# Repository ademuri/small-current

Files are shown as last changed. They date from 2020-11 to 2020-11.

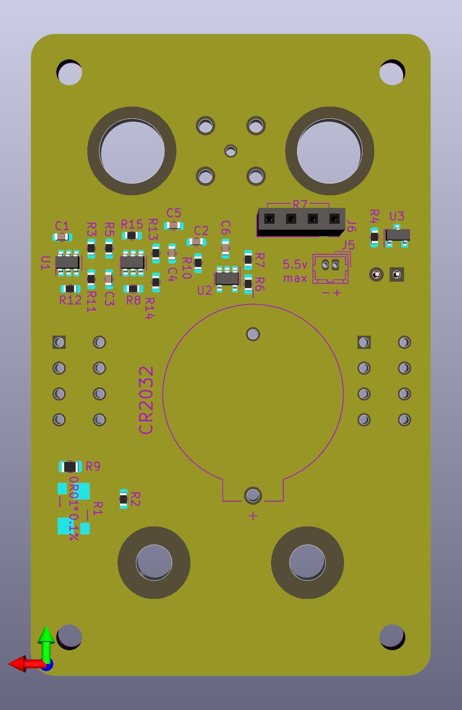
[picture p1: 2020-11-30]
ref/board back.jpg

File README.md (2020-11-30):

# smallCurrent

This library is an adaptation of the circuit schematics of the
[tinyCurrent](https://github.com/nfhw/tinycurrent) project by n-fuse, which in
turn are adapted from [uCurrent
Gold](https://www.eevblog.com/projects/ucurrent/) by Dave Jones of EEVBlog.

This is functionally equivalent to the tinyCurrent. The BOM is optimized for
ordering from Digikey (easier to source the components in North America). It has
also been redesigned in the free and open-source KiCAD, rather than Altium, so
that making changes is more accessible.

## License

This work is licensed under a [Creative Commons Attribution-ShareAlike 3.0 Unported](https://creativecommons.org/licenses/by-sa/3.0/).

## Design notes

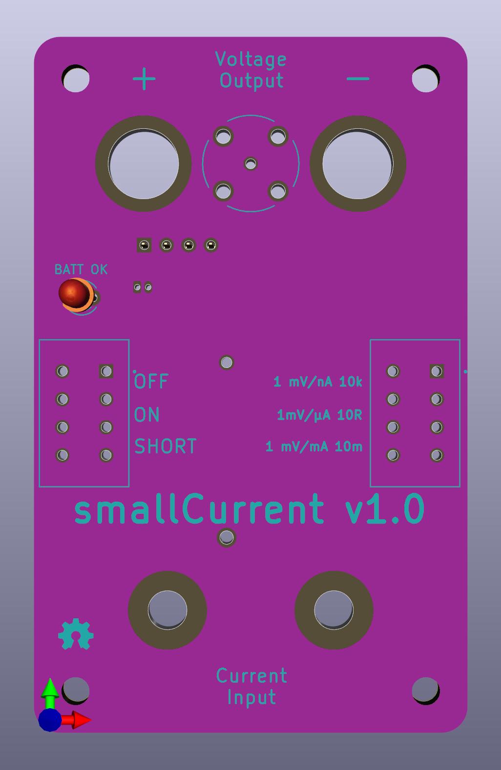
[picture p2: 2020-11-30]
ref/board front.jpg

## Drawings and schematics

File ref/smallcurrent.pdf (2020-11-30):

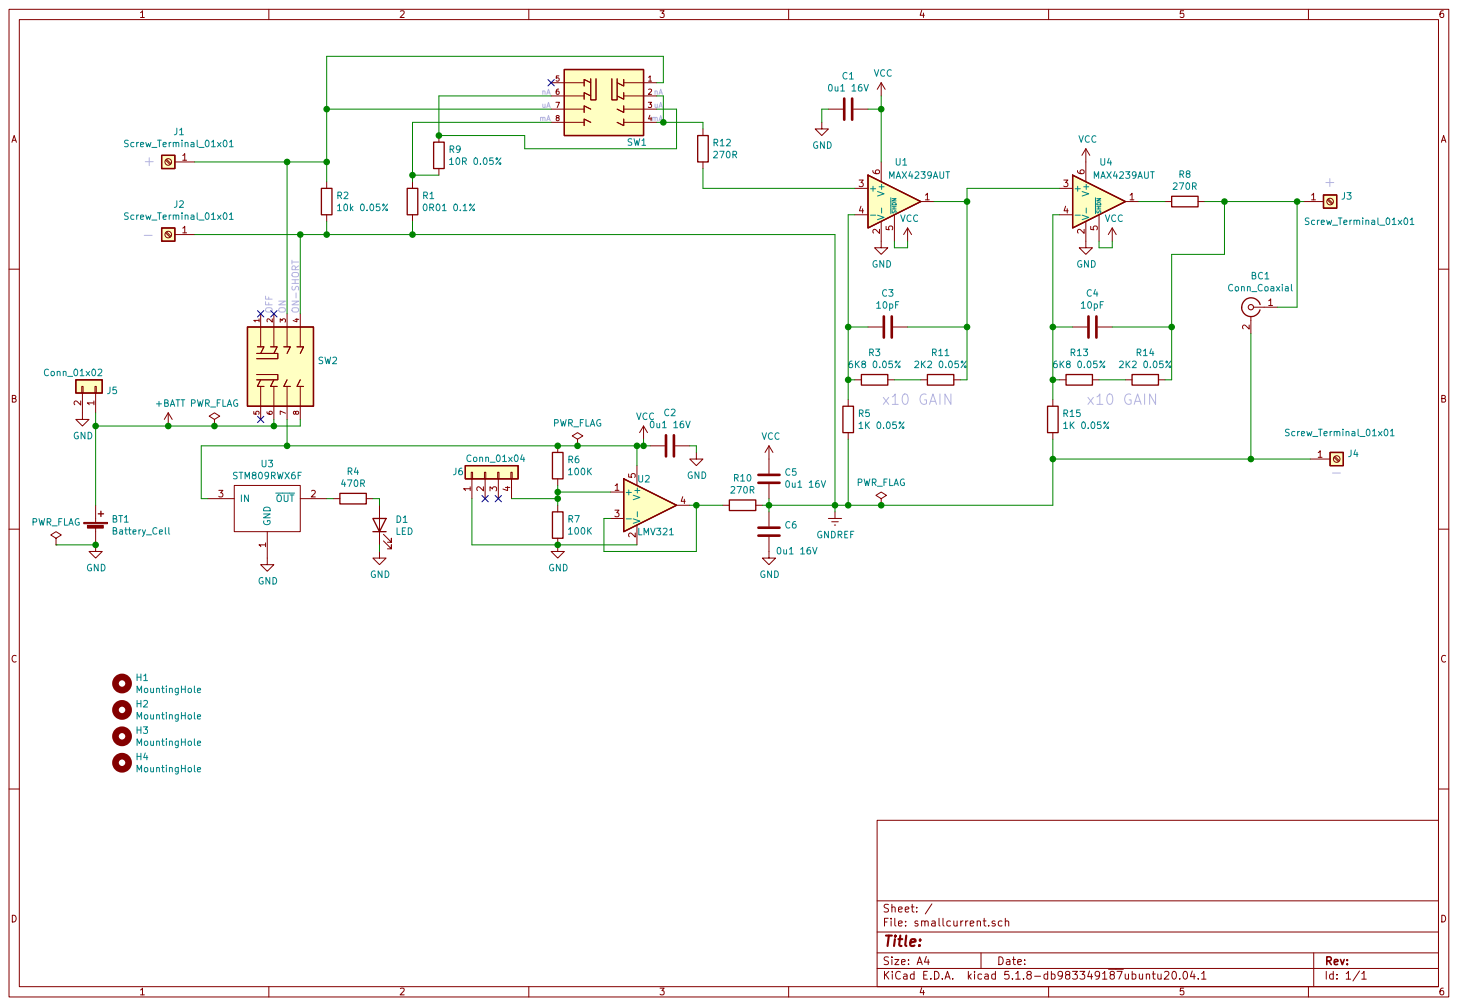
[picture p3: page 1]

Id: 1/1 Title: File: smallcurrent.sch Sheet: / GND

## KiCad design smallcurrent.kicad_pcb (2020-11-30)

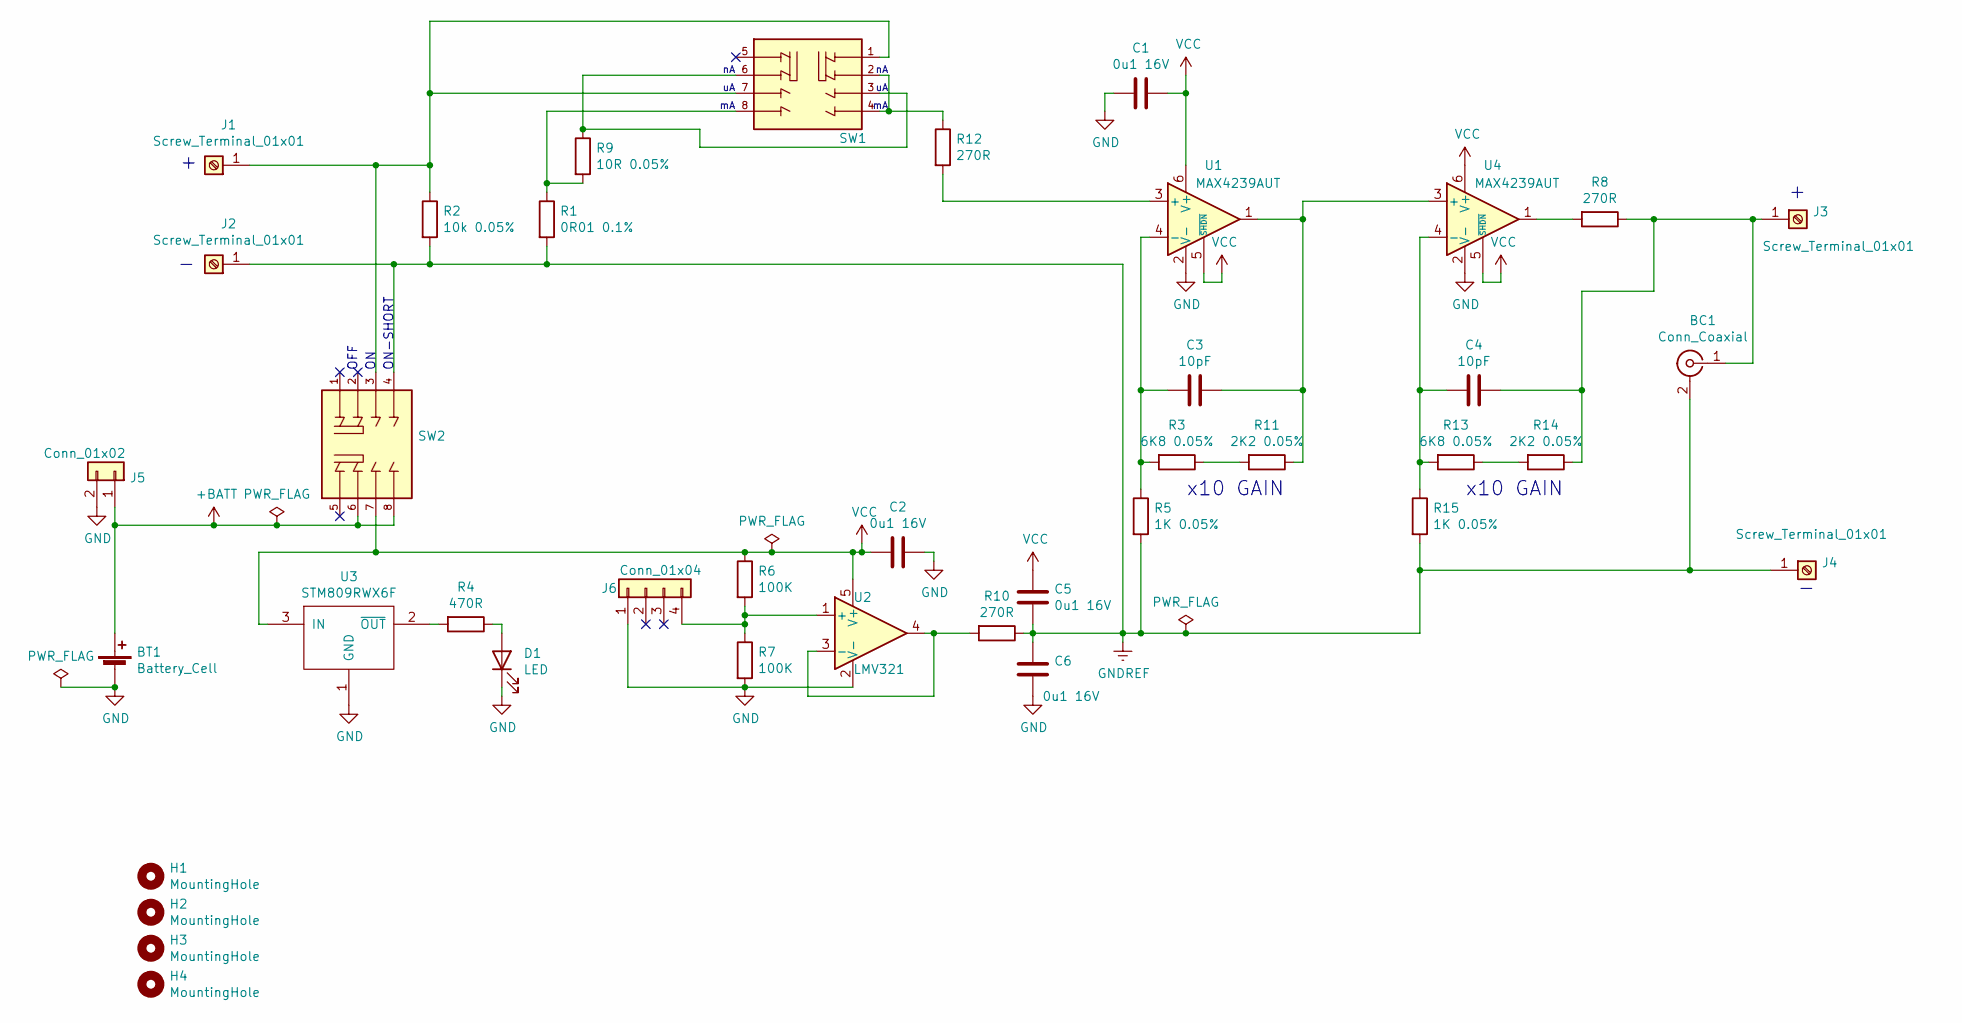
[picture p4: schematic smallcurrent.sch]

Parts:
BC1: Conn_Coaxial; TE_5-1634503-1
BT1: Battery_Cell; BAT_BS-7
C1, C2, C5, C6: 0u1 16V; C_0603_1608Metric
C3, C4: 10pF; C_0603_1608Metric
D1: LED; LED_D3.0mm
H1, H2, H3, H4: MountingHole; MountingHole_3.2mm_M3
J1, J2: Screw_Terminal_01x01; 111-0703-001_BANANA_BINDING_POST
J3, J4: Screw_Terminal_01x01; CT2230-BANANA-JACK
J5: Conn_01x02; Hirose_DF13-02P-1.25DSA_1x02_P1.25mm_Vertical
J6: Conn_01x04; PinSocket_1x04_P2.54mm_Vertical
R1: 0R01 0.1%; Y14870R01000B9R
R2: 10k 0.05%; R_0603_1608Metric
R3, R13: 6K8 0.05%; R_0603_1608Metric
R4: 470R; R_0603_1608Metric
R5, R15: 1K 0.05%; R_0603_1608Metric
R6, R7: 100K; R_0603_1608Metric
R8, R10, R12: 270R; R_0603_1608Metric
R9: 10R 0.05%; R_0805_2012Metric
R11, R14: 2K2 0.05%; R_0603_1608Metric
SW1: OS203013MT8QN1-snapeda-OS203013; SW_OS203013MT8QN1; PARTREV 8 aug 17
SW2: OS203013MT8QN1; SW_OS203013MT8QN1; PARTREV 8 aug 17
U1, U4: MAX4239AUT; SOT-23-6
U2: LMV321; SOT-23-5
U3: STM809RWX6F; SOT-23

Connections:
+BATT: BT1.1 (+), J5.1, SW2.6, SW2.8
GND: BT1.2 (-), C1.2, C2.1, C6.1, D1.1 (K), J5.2, J6.1, R7.2, U1.2 (V-), U2.2 (V-), U3.1 (GND), U4.2 (V-)
GNDREF: BC1.2 (Ext), BC1.3, BC1.4, BC1.5, C5.1, C6.2, J2.1, J4.1, R1.2, R2.2, R5.2, R10.1, R15.2, SW2.4
unnamed: BC1.1 (In), C4.2, J3.1, R8.1, R14.1
unnamed: C3.1, R3.2, R5.1, U1.4 (-)
unnamed: C3.2, R11.1, U1.1, U4.3 (+)
unnamed: C4.1, R13.2, R15.1, U4.4 (-)
unnamed: D1.2 (A), R4.1
unnamed: J1.1, R2.1, SW1.1, SW1.7, SW2.3
unnamed: J6.4, R6.2, R7.1, U2.1 (+)
unnamed: R1.1, R9.2, SW1.8
unnamed: R4.2, U3.2 (~OUT)
unnamed: R8.2, U4.1
unnamed: R9.1, SW1.3, SW1.6
unnamed: R10.2, U2.3 (-), U2.4
unnamed: R3.1, R11.2
unnamed: R12.1, SW1.2, SW1.4
unnamed: R12.2, U1.3 (+)
unnamed: R13.1, R14.2
VCC: C1.1, C2.2, C5.2, R6.1, SW2.7, U1.5 (~SHDN), U1.6 (V+), U2.5 (V+), U3.3 (IN), U4.5 (~SHDN), U4.6 (V+)

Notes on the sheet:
OFF
ON-SHORT
x10 GAIN

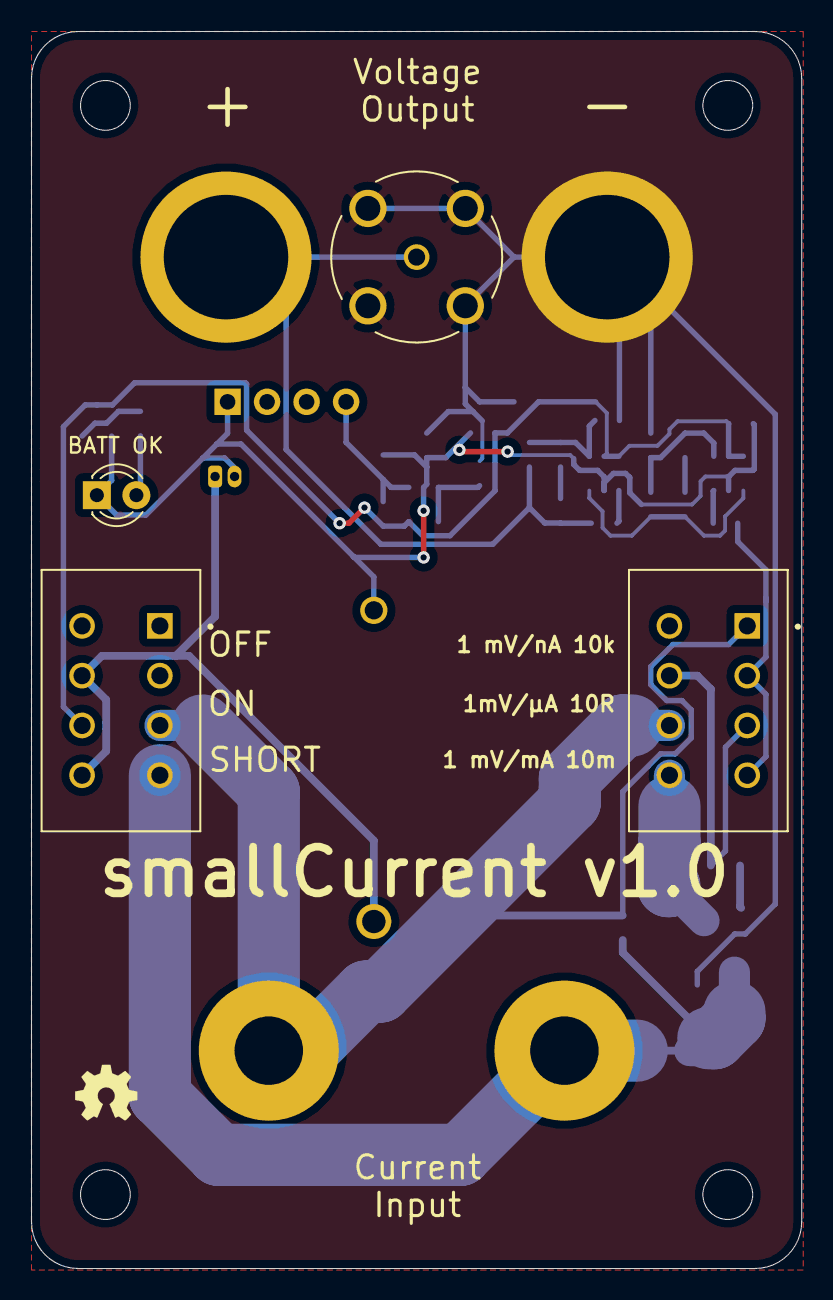
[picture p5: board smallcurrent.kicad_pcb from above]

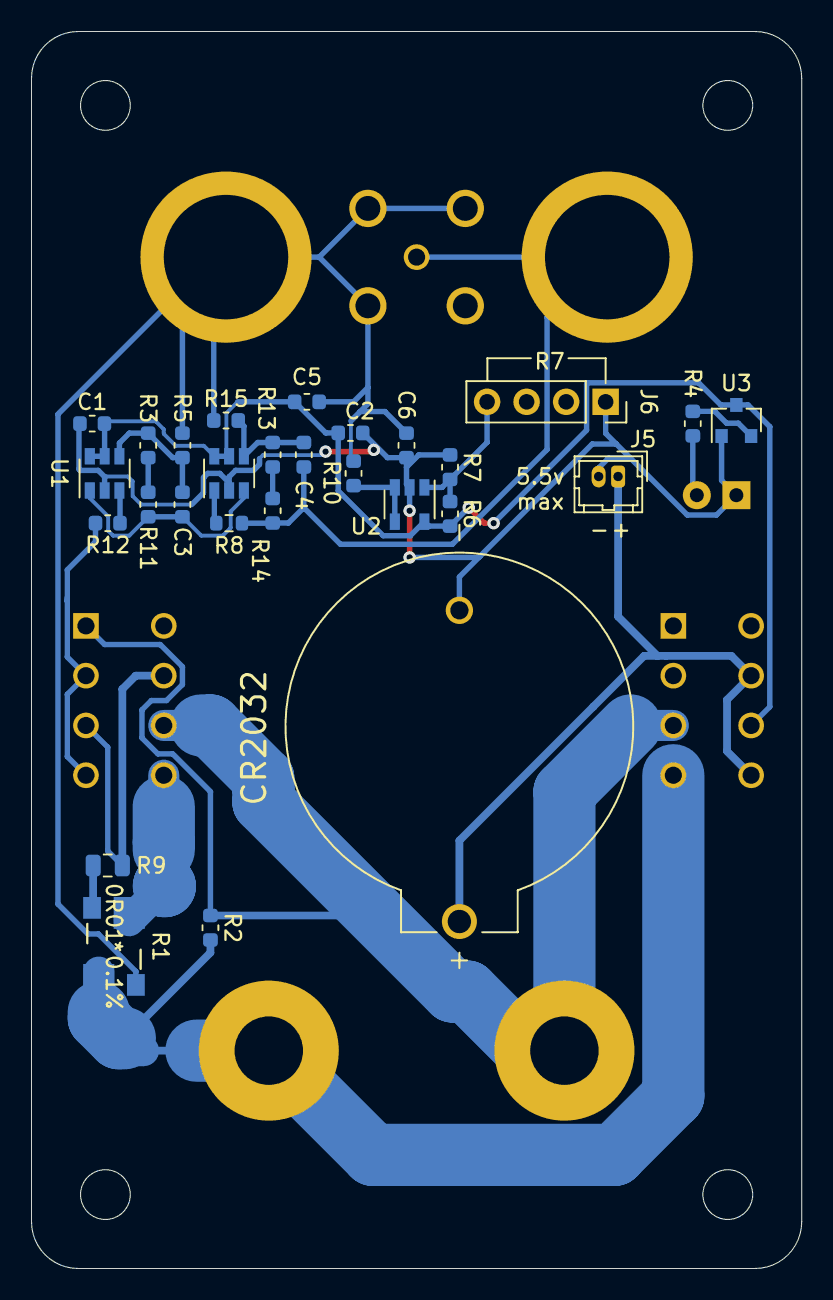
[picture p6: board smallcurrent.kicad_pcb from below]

Board: 2 copper layers, 49.5 x 79.5 mm, 40 parts (28 on the bottom side), 20 nets.

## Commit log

2020-11-21 Add schematic
    [smallcurrent.kicad_pcb, smallcurrent.sch]
2020-11-23 Add footprint associations
    [smallcurrent.sch]
2020-11-23 Start layout
    [smallcurrent.kicad_pcb, smallcurrent.sch]
2020-11-25 More layout: most parts in position
    [smallcurrent.kicad_pcb, smallcurrent.sch]
2020-11-30 Version 1.0
    [smallcurrent-B_Cu.gbr, smallcurrent-B_Mask.gbr, smallcurrent-B_Paste.gbr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]
2020-12-10 Add interactive bom

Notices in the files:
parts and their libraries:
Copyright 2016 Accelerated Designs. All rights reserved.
